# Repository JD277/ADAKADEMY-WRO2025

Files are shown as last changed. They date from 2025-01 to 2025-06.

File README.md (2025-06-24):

## Intro

This is the official Github repository for The Adakademy Team, before known as Adagroup, conformed by Jesser Palma, Jesús Alcalá and Hector Cartagena. This repository contains all the code, documentation, and resources for our project, HALBI. This is our third year participating in WRO

---
# Team Members

* Jesús Alcalá, 20 years old, jdam5000@gmail.com
* Héctor Cartagena, 18 years old, cartagenahector0608@gmail.com
* Jesser Palma, 20 years old, jssrpalma3@gmail.com
---
# Folders structure 
```
ADAKADEMY-WRO2025/
├── models/
├── other/
├── schemes/
├── src/
├── t-photos/
├── v-photos/
└── videos/
```
Where:

- `models`: Every 3D/CAD file used in the car. [view](./models/README.md)
- `schemes`: Wiring diagram, assembly explanation and components description. [view](./schemes/README.md)
- `src`: All code necessary to control the robot. [view](./src/README.md) 
- `t-photos`: team photos. [view](./t-photos/README.md)
- `v-photos`: vehicle photos. [view](./v-photos/README.md)
- `videos`: performance videos of the robot. [view](./videos/README.md)

## Our last prototype
At first, we planned to design the car from scratch, modeling and printing our own 3D pieces, including the chassis and direction, Although it seemed like a good idea at first, as we progressed we started to face problem after problem, we realized that our current design would give us more problems, at the end we tried our best with the time constraints we had, and this was the vehicle we presented at WRO 2024, Cybercooper.

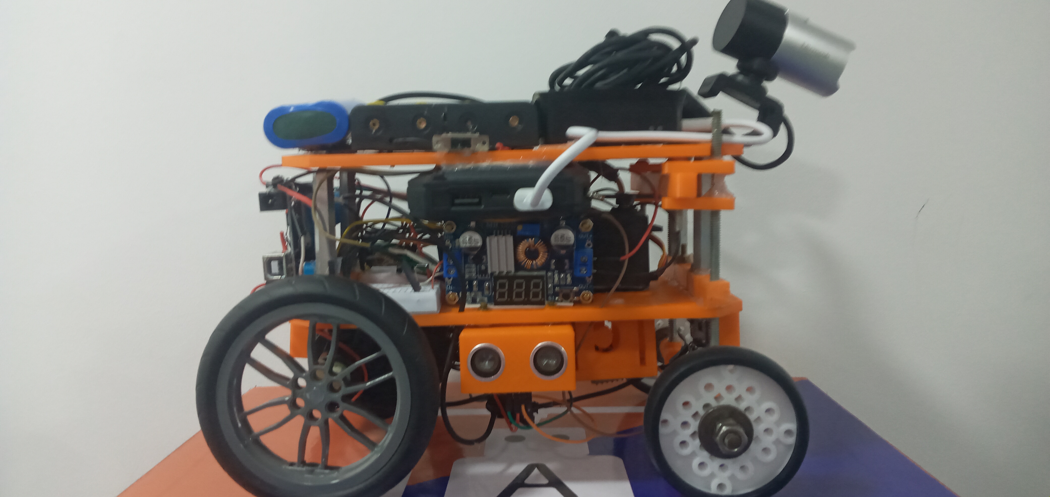
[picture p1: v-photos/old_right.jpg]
cybercooper


## Dark halbi (Our current prototype)

Given the resources we currently had, our main idea was to re-design Cybercooper, modifying the existing base, strategy and using better electronic components; we started printing the new parts with white material and thinking of better ways to assemble the car direction.

At the end, we decided to use a premade base for the chassis, the main reason for this was to save time ( and headaches) with the mechanical design, giving us more time to focus on the electronics and programming.

So we bought the maker kit car from the german enterprise **[Fischertechnik](https://www.fischertechnik.de/de-de/produkte/maker/571900-maker-kit-car)**, now we present a more profesional approach with a better documentation and totally new code sctucture,

<div align="center">

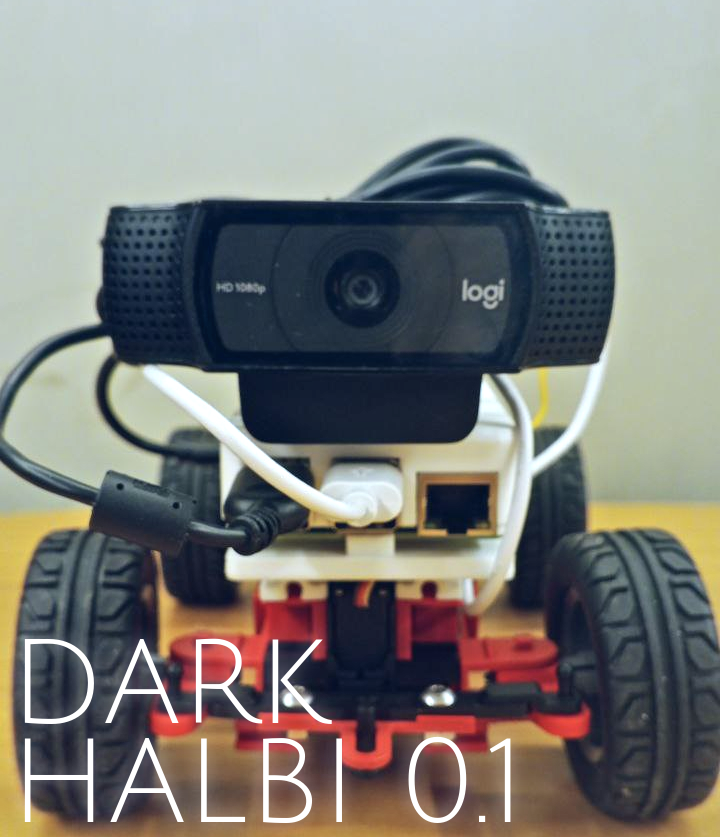
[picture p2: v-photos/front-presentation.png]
dark halbi


</div>

As the kit is made of parts like lego we just design pieces to be compatible with the chassis, after we designed the pieces we fixed the components with screw/glue/Double-side tape. But our inspiration it continues being the Cybertruck of tesla. We have many goals and we are excited about the future because each year we get better to bring betters solutions.

<div align="center">

Cybertruck
</div>

## Mobility

Our vehicle is made the [Ackermann steering mechanism](https://www.youtube.com/results?search_query=ackermann+geometry), which is a geometric  configuration used in vehicle steering systems to ensure that when turning, the inner and outer wheels travel along different radii, preventing tire scrubbing and maximizing cornering stability. This is achieved by steering the front wheels at different angles, with the inner wheel turning at a greater angle than the outer wheel. And is propelled by a differential that we explain with detail here

## Software

We developed the software using python3 as our main programming language and using Thonny/Terminal as code editor.

We wanted to keep the code as simple as possible and use a single language, in order to make this possible we used a library called Pyfirmata which enables us to merge the microcontroller code and the raspberry code in a single unit. 

#### Image Processing

We use the raspberry camera to capture the image, which is converted from BGR format to LAB `(lightness, green-red, blue-yellow)`. We use this colorspace because it's easier to detect the colors, regardless of the environment lighting.

We then use OpenCV to apply a threshold to the image, which returns a mask image with the pixels that reside within the specified color range, we can also reduce processing time by only searching within a specific region of interest on the screen.

### Obstacle Detection

For Obstacle detection, we specify various color ranges that coincide with the color of the obstacles, red and green. After the camera captures the image, we apply gaussian blur and median filters to get a sharper image, the program then applies thresholds to get masks with the colors we are interested in, with this mask we can detected the screen position of the obstacles and the contours of the circuit wall, which can be used to decide the turning direction of the car based on a proportional derivative (PD) algorithm, which involves calculating the differences between the area of the walls.

Looking for more? go to projects folders [Here](#folders-structure) !

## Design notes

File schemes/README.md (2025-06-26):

# Hardware documentation and setup guide
This section provides an overview of the hardware components  used in our autonomous vehicle for the WRO 2025 competition. It includes a detailed description of the electronic and mechanical parts, their specifications, and how they are integrated into the robot’s design. The goal is to document our choices clearly and technically, following the WRO 2025 requirements for engineering transparency and reproducibility. 

## Table of content

* [List of components](#list-of-components)

* [Components description](#components-description)
  
  *  [Raspberry PI 4 B](#raspberry-pi-4-b)

  * [Fischertechnik kit](#fischertechnik-kit)

  * [Li-on 18650 batteries, LX-2BUPS MT3068](#li-on-18650-batteries-lx-2bups-mt3068)

  * [Arduino nano](#arduino-nano)

  * [L298n](#l298n)

  * [Fischertechnik Micro servo Nr. 132292](#fischertechnik-micro-servo-nr-132292)

  * [Ecorder motor 9v Nr. 153422](#ecorder-motor-9v-nr-153422)

  * [Logitech C920X](#logitech-c920x)

* [Assembly](#assembly)
  * [Wiring diagram](#wiring-diagram)
  * [Power description](#power)
  * [Drive](#drive)
  * [3D desing proccess and assembly](#3d-desing-proccess-and-assembly)

* [Recommendations for future fevelopment](#recommendations-for-future-development)
## List of components

<div align="center">

| Quantity | Product | Price| Total |
|---|---|---|---|
| 1 | [Raspberry Pi 4 B](https://www.amazon.com/Raspberry-aleaci%C3%B3n-resistente-refrigerada-ventilador/dp/B07XTRK8D4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) | $110.00 | $110.00 |
| 1 | [Car chassis with motor and servo](https://www.amazon.com/-/es/fischertechnik-Maker-Kit-Car-571900/dp/B0CY31DGT1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) | $152.00 | $152.00 |
| 4 | [18650 Batteries x 2](https://articulo.mercadolibre.com.ve/MLV-822728792-bateria-de-litio-recargable-18650-37v-7800mah-_JM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) | $10.00 | $20.00 |
| 1 | [Webcam logitech](https://www.amazon.com/Logitech-correcci%C3%B3n-funciona-Facetime-port%C3%A1til/dp/B085TFF7M1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) | $70.00 | $70.00 |
| 1 | [MT6068](https://www.amazon.com/-/es/Buying-M%C3%B3dulo-impulso-ajustable-MT3608/dp/B0CWKWX7QC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) | $3.00 | $3.00  |
| 1 | [L298N](https://www.amazon.com/-/es/WWZMDiB-L298N-controlador-Arduino-Raspberry/dp/B0CR6BX5QL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) | $5.00 | $5.00  |
| 1 | [Arduino nano](https://www.amazon.com/-/es/Nano-conexi%C3%B3n-compatible-Arduino-V3-0/dp/B0B42GRG15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) | $10.00 | $10.00 |
| 2 | [LX-2BUPS 5v](https://www.amazon.com/-/es/Bater%C3%ADa-M%C3%B3dulo-Cargador-Tablero-Indicador/dp/B0CGZS38QR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) | $5.24 | $10.48 |
| 2 | [USB cable type C](https://www.amazon.com/paquete-cables-trenzados-iPhone-Samsung/dp/B0DPMQ7291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) | $6.00 | $12.00 |
| 2 | ON OFF Switch | $2.5 | $5.00 |
| 1 | [Indications LEDs](https://www.amazon.com/-/es/MCIGICM-circuitos-experimentos-cient%C3%ADficos-multicolor/dp/B07PG84V17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) | $4 | $4.00 |
| **Total** | | | **$401.48** |

</div>

---

<div style="text-align:justify">

## Components description

### Raspberry PI 4 B  

The Raspberry Pi 4 Model B  is a powerful, credit-card-sized single-board computer (SBC)  developed by the Raspberry Pi Foundation. It is widely used in robotics, IoT projects, and embedded systems due to its versatility, performance, and affordability. 

<div align="center">

Raspberry

</div>

Our strategy is centered on computer vision algorithms developed by us using **[Opencv](https://opencv.org/)** with python, for that reason we have choose this computer given that have a low electrcity consumption (5v 3A) contrary to the pi 5 (5V 5A 😬 To high!) besides is better option that the pi 3 B that we used the last time.

These are the features of our raspberry PI 4:

<div align="center">

| Feature | Description |
|---|---|
| **Type** | Single-Board Computer (SBC) |
| **Processor** | Quad-core Cortex-A72 (ARM v8) @ 1.5GHz |
| **Memory (RAM)** | 8GB |
| **Storage** | microSD card slot |
| **Connectivity** | Wi-Fi 802.11ac (2.4 GHz / 5 GHz), Bluetooth 5.0, Ethernet |
| **USB Ports** | 2 x USB 3.0, 2 x USB 2.0  |
| **Video Output** | 2 x micro-HDMI ports supporting up to 4K resolution |
| **Camera Support** | MIPI CSI camera interface |
| **GPIO Pins** | 40-pin GPIO header (supports I²C, SPI, UART, PWM) |
| **Operating System** | Raspberry Pi OS |
| **Power Supply** | 5V / 3A via USB-C port |

</div>

---
### Fischertechnik kit 
The Fischertechnik Maker Kit Car is a pre-assembled chassis that provides a solid foundation for creating functional models or prototypes of vehicles. It includes essential components such as wheels, motors, axles, and structural elements that allow users to build a stable base for their projects. The kit is compatible with various motors, sensors, and other electronic components, making it ideal for integrating advanced functionalities like autonomous driving, obstacle avoidance, or remote control. The design is modular, enabling easy modifications and upgrades as needed. This flexibility allows users to experiment with different configurations and mechanical setups without needing to start from scratch.

Kits like this are ideal for teams new to robotics because they eliminate the need for extensive mechanical assembly or 3D modeling skills. By using a pre-assembled kit, you can focus on higher-level tasks such as programming, sensor integration, and algorithm development without worrying about building the physical structure from scratch. This approach is particularly beneficial for educational purposes, as it allows students to quickly prototype ideas and test concepts without getting bogged down by mechanical complexities. Additionally, many international teams use similar kits, making it a widely accepted and practical choice for competitions like the World Robot Olympiad (WRO).

<div align="center">

<div style="width:290px">

halbi

</div>
</div>

While pre-assembled kits offer convenience, designing and 3D-printing your own chassis provides several advantages. First, custom chassis designs allow for greater flexibility and optimization, enabling you to tailor the vehicle to specific requirements such as weight distribution, component placement, and cost-efficiency. A well-designed custom chassis can also be more durable and reliable than off-the-shelf kits, which may have fragile parts that are not easily replaceable. Furthermore, creating your own chassis fosters deeper learning in mechanical engineering, CAD modeling, and prototyping—skills that are highly valued in robotics and engineering competitions. While it requires more time and technical expertise upfront, the ability to iterate and refine your design based on testing results leads to a more robust and competitive robot. Ultimately, while pre-assembled kits are great for getting started, building your own chassis offers superior customization, cost savings, and educational value, making it the preferred choice for advanced teams aiming to push the boundaries of innovation in the WRO FE category.

---
### Li-on 18650 batteries, LX-2BUPS MT3068

The robot uses two 18650 Li-ion batteries  combined with an LX-2BUPS MT3068 power management module , which allows the system to function without complex circuitry or custom-built charging solutions. This setup provides a stable power source for both the Raspberry Pi and motor driver, making it suitable for teams without advanced electronics experience. The LX-2BUPS module acts as a UPS (uninterruptible power supply), ensuring smooth transitions between charging and discharging states. However, this configuration has some limitations: the 18650 batteries are relatively large, making space management within the chassis challenging. Additionally, these batteries have limited runtime when powering high-consumption components like the Raspberry Pi, especially during intensive tasks such as image processing. 

To address voltage requirements for the motors, we included a step-up module to boost the output to 11.24V , allowing the motors to operate at optimal speed. While this setup works well for basic operation, it lacks a Battery Management System (BMS) , meaning there’s no automatic balancing of charge between the two batteries. As a result, one battery may discharge faster than the other, potentially leading to unstable power delivery or overheating. Despite its drawbacks, this energy solution was chosen because our team lacked the expertise to design and implement a more advanced Li-Po-based system from scratch. It serves as a functional starting point that enables us to focus on software and sensor integration while preparing for future improvements through custom-designed power circuits. 

<div align="center">

<div style="width:290px">

LX2-BUSB

mt3068

</div>
</div>

---
### Arduino nano
For our autonomous vehicle project, we chose the Arduino Nano with USB-C  as the primary microcontroller to handle sensor inputs, motor control, and coordination with the main Single-Board Computer (SBC), such as a Raspberry Pi. This decision was driven by both practical and ergonomic considerations—primarily, our team’s preference for the USB-C interface , which offers better durability, faster data transfer, and reversible plug orientation compared to older micro-USB connectors. 

While the Arduino Nano (USB-C version) is not strictly required for this project, its compact size, wide community support, and compatibility with the Firmata2 protocol  made it a natural fit for rapid prototyping and integration with Python-based control logic running on the SBC. 
this are some features from our arduino :
<div align="center">

| Feature | Description |
|---|---|
| **Type** | Microcontroller board |
| **Microcontroller** | ATmega328P (Nano v3) |
| **Clock Speed** | 16 MHz |
| **Flash Memory** | 32 KB (0.5 KB used by bootloader) |
| **SRAM** | 2 KB |
| **EEPROM** | 1 KB |
| **Digital I/O Pins** | 14 (of which 6 provide PWM output) |
| **Analog Input Pins** | 8 channels with 10-bit resolution |
| **Power Supply** | 5V regulated input |
| **Input Voltage (recommended)** | 7–12V |
| **Current Draw (typical)** | ~20 mA |
| **Communication Interfaces** | UART, SPI, I²C |
| **Programming Language** | C/C++ using Arduino IDE or PlatformIO |

<div style="width:290px">
</br>

nano

</div>

</div>

---
### L298n
The L298N H-Bridge module  is a dual motor driver commonly used in robotics to control the direction and speed of DC motors. It allows bidirectional motor control using Pulse Width Modulation (PWM) signals from microcontrollers like Arduino or Raspberry Pi. This makes it ideal for basic robotic platforms where simplicity and ease of use are prioritized over high efficiency. 

While the L298N is user-friendly and widely available, it has some limitations such as high voltage drop  (around 1.5V–3V per motor), which reduces the effective voltage delivered to the motors. This can affect performance, especially when using lower-voltage batteries. Additionally, it tends to generate significant heat , often requiring heatsinks or cooling solutions during prolonged operation. We don't opt for more efficient drivers like the DRV8833  or TB6612 , which offer better energy efficiency and thermal performance because find or deliver those drivers for Venezuela is very hard. However, for early development and testing, the L298N remains a solid choice due to its ease of integration and widespread community support.

<div align="center">

<div style="width:290px">

L298N

</div>
</div>

---
### Fischertechnik micro servo Nr. 132292
A servomotor  (or servo) is a type of motor commonly used in robotics, automation, and control applications where precise angular positioning  is required. Unlike regular DC motors that rotate continuously, servos are designed to move to a specific angle and hold that position until instructed otherwise.

A standard **servomotor** consists of:

1. **DC Motor**: Provides rotational force.
2. **Gear Reduction System**: Slows down the motor’s rotation and increases torque.
3. **Position Sensor (Potentiometer)**: Monitors the current shaft position.
4. **Control Circuitry**: Compares the desired position with the actual one and adjusts the motor accordingly.

Servos receive **control signals** through Pulse Width Modulation (PWM). The width of the pulse determines the angle the motor should turn to:

- **~50 Hz signal (every 20 ms)**
- **Pulse width determines position:**
  - `1.0 ms` → ~**0°**
  - `1.5 ms` → ~**90° (neutral)**
  - `2.0 ms` → ~**180°**

This makes servos ideal for our ackerman direction. Here are some features from that servo:

<div align="center">

| Feature | Description |
|---|---|
| **Voltage Range** | 4.8V – 6.0V |
| **Control Signal** | PWM (Positive Edge Triggered) |
| **Neutral Position** | Approx. 1500 µs (microseconds) |
| **Rotation Angle** | ~60° ±10° |
| **Torque @ 4.8V** | 1.8 kg·cm |
| **Torque @ 6.0V** | 2.2 kg·cm |
| **Speed @ No Load** | 0.13 sec/60° at 4.8V / 0.11 sec/60° at 6.0V |
| **Dead Band Width** | 8 µs |
| **Current Consumption (Idle)** | 200 mA stopped / 1000 mA running (no load) |
| **Wire Length** | 240 mm |
| **Plug Type** | JR Universal (Brown = GND, Red = VCC, Orange = Signal) |

<div style="width:290px">
</br>

Servo

</div>
</div>

**NOTE:** You can use other servo if you can adapt it to the kit but you don't have to use exact the same 

---
### Ecorder motor 9v Nr. 153422

An **encoder motor** is a DC motor equipped with an **integrated encoder**, which allows for **precise measurement of rotation speed, direction, and position**. This feedback makes it ideal for applications that require accurate motion control, such as autonomous navigation, distance estimation, or path correction. The encoder generates electrical pulses as the motor shaft rotates, and by counting these pulses, the robot can determine how far it has traveled or how fast it is moving, but we're only using the motor wihtout sensing the position of the motor.

Here are the motors features:

<div align="center">

| Feature | Description |
|---|---|
| **Supply Voltage** | 9V DC (motor side), 3.3–9V DC (encoder side) |
| **Encoder Type** | Push-Pull Output (0/9V), max. 10 mA |
| **Resolution** | 3 pulses per motor revolution (or 6 when counting both rising and falling edges) |
| **Gear Ratio** | 1:21.3 |
| **Encoder Frequency** | Up to 1 kHz |
| **Signal Interface** | 3-pin header |
| **No-Load Speed** | ~200 rpm (±22) at 9V |
| **Stall Torque** | 1.3 kg·cm minimum |
| **Stall Current** | 1.3A maximum |

<div style="width:290px">
</br>

Encorder

</div>
</div>

---
### Logitech C920X

The **Logitech C920X** is a high-definition USB webcam designed for video conferencing, streaming, and general-purpose imaging applications. It features a **1080p HD sensor** with autofocus, built-in microphone array, and compatibility with most operating systems, making it a versatile vision sensor for robotics projects.

In our autonomous vehicle setup, we use the **C920X as the primary camera** for visual perception tasks such as:
- Line detection (blue and orange lines)
- Obstacle avoidance
- Traffic sign recognition
- Parking alignment using color-based segmentation

<div align="center">

| Feature | Specification |
|---|---|
| **Resolution** | Full HD 1080p at 30 fps |
| **Autofocus** | Yes – allows sharp image capture even while moving |
| **Microphone** | Built-in stereo microphones |
| **Compatibility** | Works with Windows, Linux, macOS |
| **Interface** | USB 2.0/3.0 (plug-and-play) |
| **Mounting Options** | Clip-on or tripod mount |
| **Field of View** | 78° diagonal field of view (ideal for line detection) |

</div>

Thanks to its **UVC (USB Video Class)** compliance, the C920X can be used directly with OpenCV and Python on platforms like Raspberry Pi without requiring special drivers. This makes it ideal for real-time image processing and autonomous decision-making in robot vehicles.

Although not originally designed for robotics, the C920X has become a popular choice among teams due to its affordability, reliability, and ease of integration with Single Board Computers (SBCs) like **Raspberry Pi**.

#### 🚫 Limitations

- **Fixed Focus:** While it has autofocus, lighting conditions affect performance significantly.
- **No Hardware Trigger:** Not ideal for synchronized sensor fusion but acceptable for basic vision tasks.
- **Size and Weight:** Slightly bulkier than alternatives like the Arducam or Raspberry Pi HQ Camera.

Despite these limitations, the **Logitech C920X** serves as an excellent starting point for building a functional vision system in the WRO 2025 competition.

<div align="center">

<div style="width:290px">

camera

</div>
</div>

---
## Assembly

To test new ways to achieve the goal and win the competition, we make a lot of investigation watching videos, others teams repositories we choose the [Maker kit car from Fischertechnik](https://www.fischertechnik.de/de-de/produkte/maker/571900-maker-kit-car) , and after testing we could notice this about our election:

- The chassis have many fragile parts.
- Have a deviation on the direction because the wheels oscillate. 
- The wheels axis are made from plastic so if you put much weight it will broke. 

So if you're starting we recommend it but we determine is better inversion to model your own chasis.

Leaving that aside, we decided to use a premade base for the chassis, the main reason for this was to save time ( and headaches) with the mechanical design, giving us more time to focus on the electronics and programming.

<div align="center">

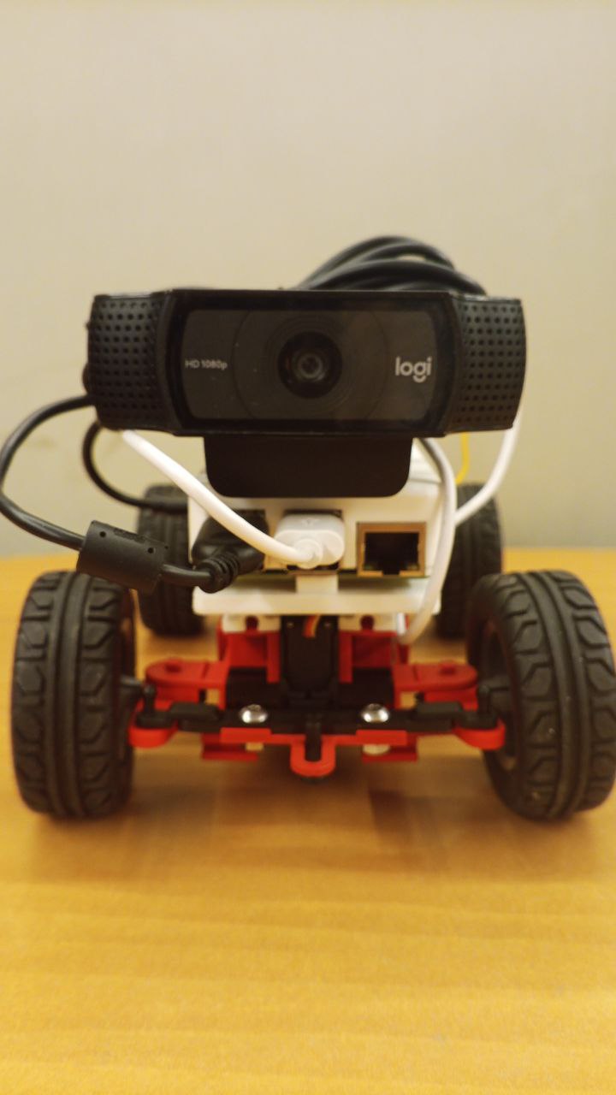
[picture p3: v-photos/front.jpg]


</div>

For the assembly we are gone suppose that you have follow the assemble instructions of the [company](https://apps.fischer.de/ecom/fischertechnik/digitale-bauanleitungen/maker-kit-car.htm), **please take in count that maybe you will have to use glue in some parts of the kit car** because the are some parts like the servo axis that are easy to remove and with the vibration it will expulse the pieces that aren't fixed pieces

---

### Wiring diagram

Remember to buy every component before start building

<div align="center">

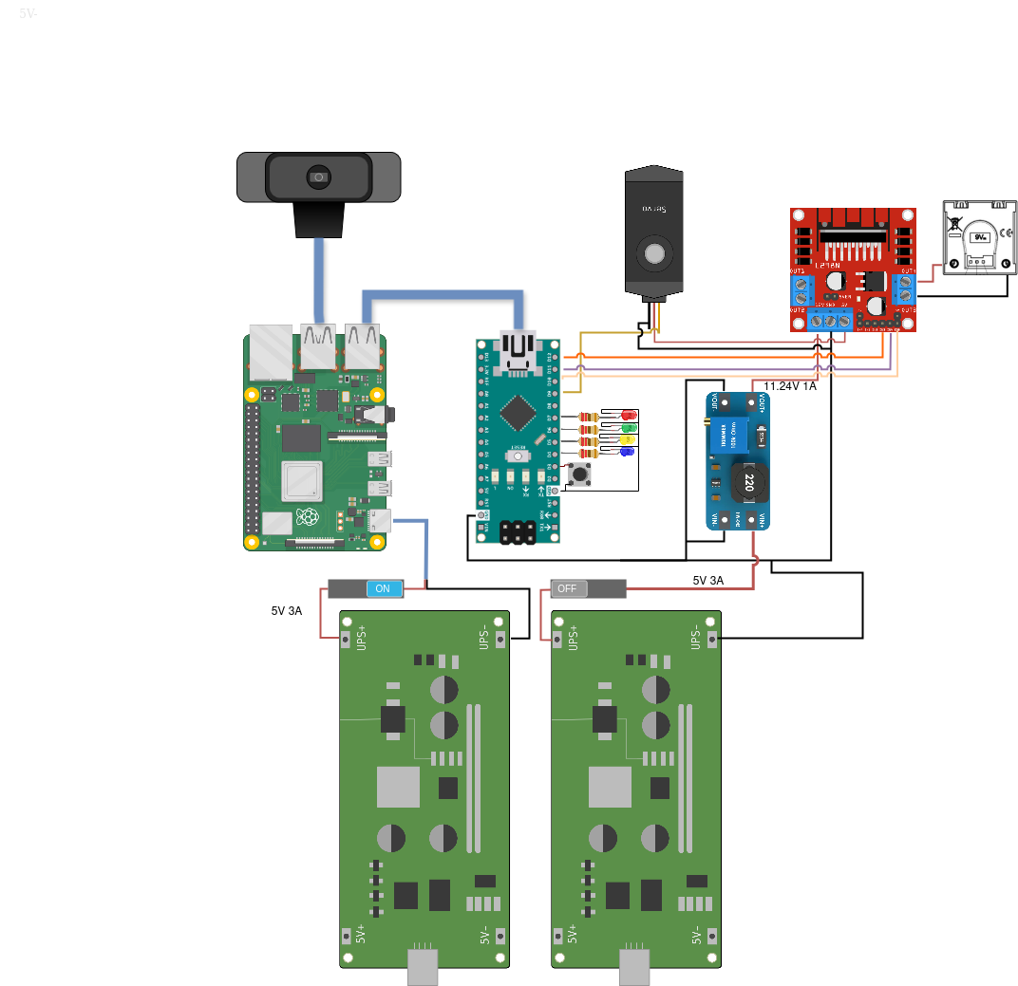
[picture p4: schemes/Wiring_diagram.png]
cables


</div>

--- 

### Power

A short explanation of the power supply hierarchy of the robot

- 18650 battery `3.7v 2000mAh` x 2
  - LX-2BUPS `5V 3A`
    - Raspberry PI 4 `5v 3A`
      - Arduino nano `5v` powered by USB C cable
      - Logitech camera
    
- 18650 battery `3.7v 2000mAh` x 2
  - LX-2BUPS `5V 3A`
    - MT3068 `5v 3A` --> `11.24v 1A`
      - L298N `12v MAX` 
        - Micro Servo `5v`
        - Encorder motor `9v`

### Drive

The kit use an simple Ackerman direction powered by a servo with 1.8kgcm standing torque, said direction is a geometric design principle used in vehicles to ensure that both front wheels turn at different angles when making a turn, allowing the vehicle to move smoothly around corners without skidding. This system uses a linkage setup that enables the inner wheel to turn sharper than the outer wheel, following the natural arc of the turn. In the Fischertechnik Maker Kit Car , the Ackermann steering mechanism is implemented using a set of tie rods connected to the front wheels. [We recommed this video to learn more about it](https://www.youtube.com/watch?v=hsQO5C0adQk)

While the propulsion is made by a mechanism called "diferential" wich  Maker Kit includes, is a mechanical system that allows the driven wheels of the vehicle to rotate at different speeds while receiving power from the same source. This is essential for smooth turning, as it enables one wheel to move faster than the other when the vehicle corners, preventing skidding and reducing tire wear. In the context of the WRO 2025 FE category, this type of differential is typically used in rear-wheel-drive configurations where an electric motor powers both rear wheels through a shared axle. While the kit’s differential simplifies the drivetrain design and improves maneuverability, it may not be suitable for advanced autonomous driving tasks due to its mechanical limitations and potential lack of precision control compared to software-based or independent motor control.

<div align="center">

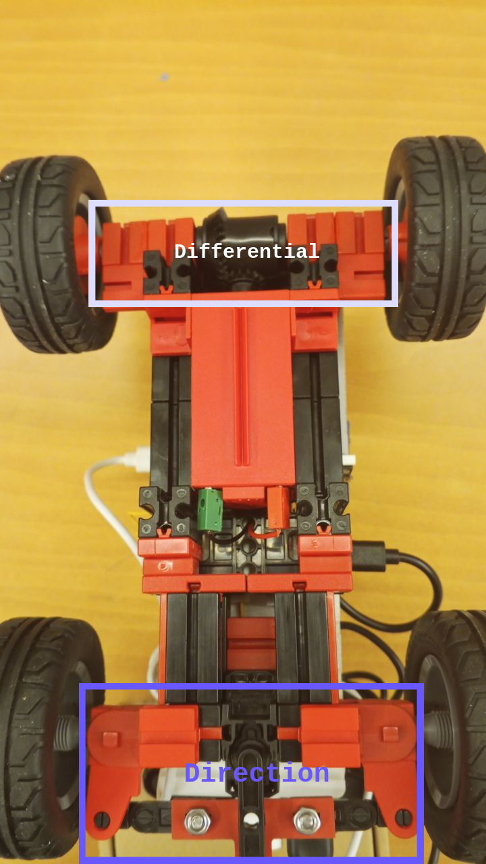
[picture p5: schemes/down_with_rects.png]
down


</div>

### 3D desing proccess and assembly

We bought the chasis and it arrives 2 months later, at the beggining we get scared because of the space so we begin to think how to save space to place every component.

After days and a lots of headaches we find the solution to put every component.

the front part of our car is essentially the [raspberry case]() elevated with [extension parts](../models/Extension%20base.3mf) desingned by our own, upper to RPI is the camera fixed with double-sided tape. The RPI is located in a way that you could use the USB ports, we choose this because we have two components that need the USB connection.

<div align="center">

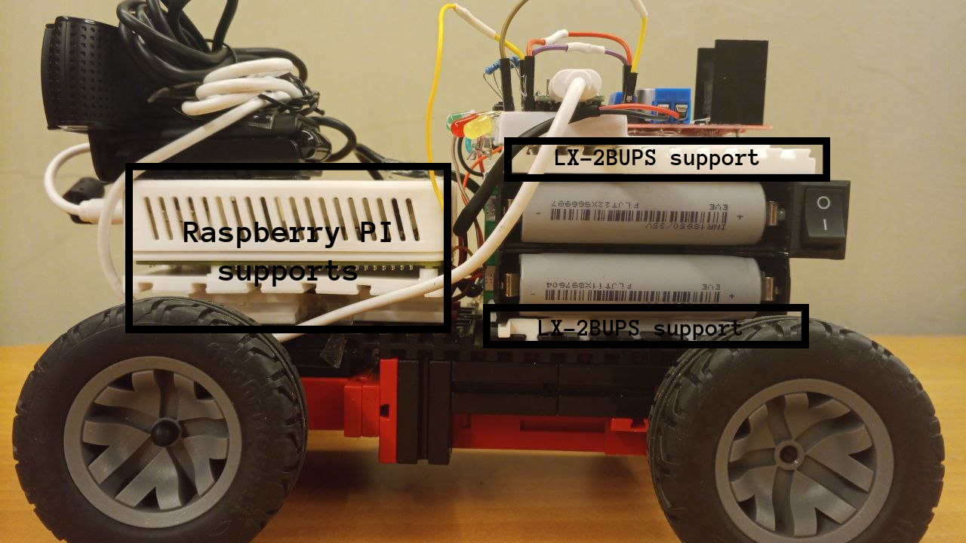
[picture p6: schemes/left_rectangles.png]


</div>

For the UPS modules we have model two supports that join both powersupply and hides almost every connection, the down part join the fits in the chasis of the maker kit car but before to put the modules you have to solder the switchs and the cables.

<div align="center">

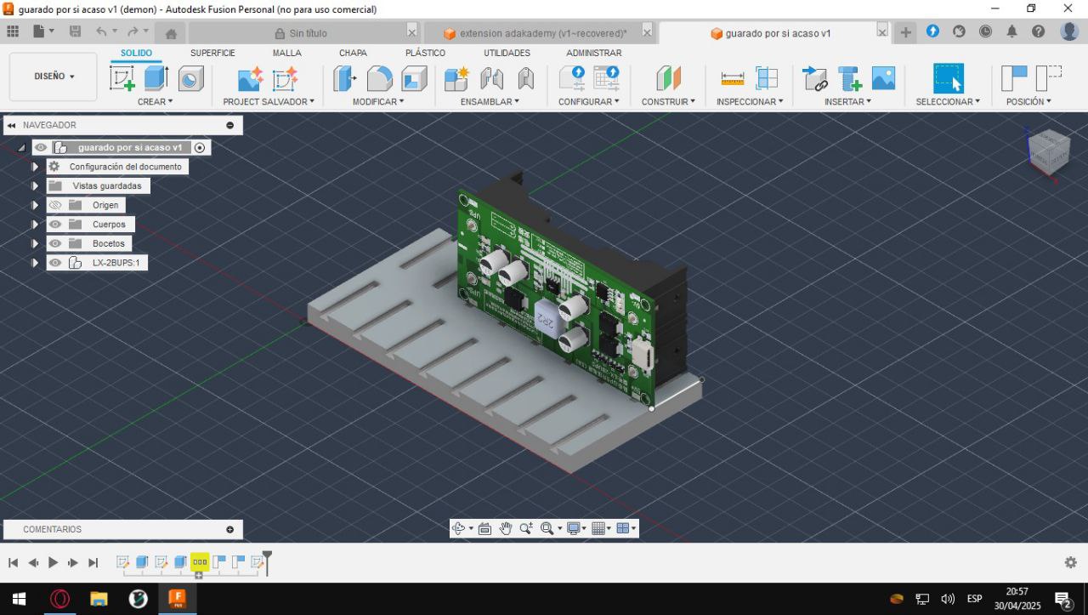
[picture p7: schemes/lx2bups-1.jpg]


</div>

In our case we fixed the switchs with industrial glue but you can do some 3d print holder for it. The top part is used as base for the nano, l298n module (wich have its own base to fit in the other one), and the mt3608.

<div align="center">

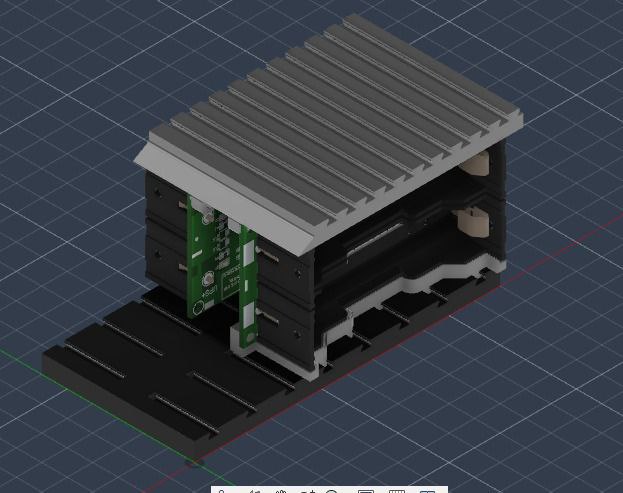
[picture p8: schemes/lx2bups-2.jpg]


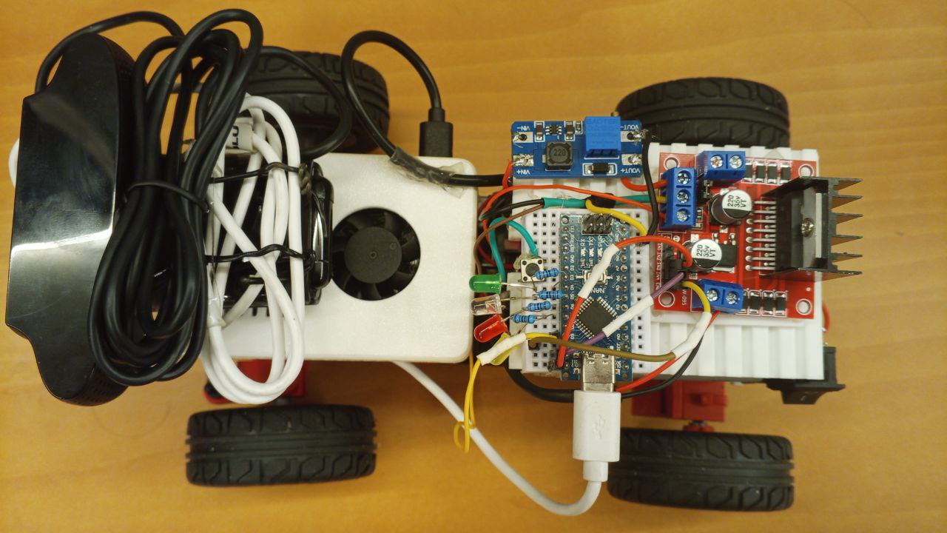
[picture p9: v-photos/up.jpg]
up


</div>

## Recommendations for future development  

As a recommendation for other teams, we suggest two key improvements to enhance both the performance and compactness of your autonomous vehicle: 

  * Design a Custom PCB: 
    Creating your own custom printed circuit board (PCB)  allows you to integrate all essential electronics — such as motor drivers, voltage regulators, microcontroller, and sensor interfaces — into a single, compact board tailored to your robot’s needs. This not only reduces the overall size but also improves reliability by minimizing loose connections and simplifying wiring. 

  * Use a LiPo Battery with Dedicated Charger: 
    Replacing standard battery packs with a LiPo (Lithium Polymer) battery  and using a dedicated charging circuit can significantly reduce weight and space usage while offering better power efficiency. LiPo batteries provide higher energy density and longer runtime, which is especially beneficial in high-drain applications like motor control and onboard computing. 

These are our goals for improvement in the next season, and we believe they will help us build a more efficient and competition-ready vehicle. 

Additionally, we recommend conducting thorough research and planning  before purchasing components. Doing a deep investigation on each part — including compatibility, power requirements, and long-term usability — helps avoid unnecessary expenses and ensures every component contributes meaningfully to the final design. 

<div>

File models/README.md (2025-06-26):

# Content
## First Prototype
- Lower Chasis
- Direction
## Fischertechnik kit
- LX-2BUPS down base
- L298n Base
- Top Base
- Base extension
- Raspberry4_Base
- wheel nut

# Overview
In this file will be the explanation of the models used for the proyect

## *First prototype (Cooper White)*
- This was the version we design in case the chasis didn´t come in time

Cooper White

## *Fischertechnik kit (The final chasis)*
- althought the chasis we planned initially did come in time 
Fischertechnik kit

##  Folder structure
The models files are organized with this order:
```
ADAKADEMY-WRO2025/models/
├── LX-2BUPS_Down_Base.3mf
├── L298N_Base.3mf
├── Top_Base.3mf
├── Wheel_nut.3mf
├── Raspberry4_Base.3mf
└── Base_Extension.3mf
```
Where:

- `/LX-2BUPS_Down_Base.3mf`: Model used to connect the LX-2BUPS module to the chassis
- `/L298N_Base.3mf`: Model used to connect the l298n module to the chassis
- `/Top_Base.3mf`: Top extension model to connect more modules to the chassis
- `/Wheel_nut.3mf`: Nut to adjust the wheels to the axle
- `/Raspberry4_Base.3mf`: Models to connect and protect the Raspberry 4 Model B to the chassis
- `/Base_Extension.3mf`: Extension model to increase the height of components by 10 mm

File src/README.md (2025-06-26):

# Software documentation

This section provides an overview of the software architecture  used in our autonomous vehicle for the WRO 2025 Futuros Ingenieros  competition. It includes:

* The programming languages and tools used

* A high-level description of the system's modules

* How the robot processes sensor data, makes decisions, and controls hardware

* Integration with vision systems (e.g., line detection, traffic sign recognition)

* Communication between controllers (e.g., Raspberry Pi ↔ Arduino Nano)

# Folders structure 
```
ADAKADEMY-WRO2025/src/
├── modules/
|    ├── board.py
|    ├── vision.py
|    └── halbi.py
├── utils/
|    ├── movement_test.py
|    ├── color_tester.py
|    └── vision_test.py
├── constants.py
├── open_challenge.py
└── obstacle_challenge.py
```
Where:

- `modules/board.py`: This is ArduinoController class manages Arduino hardware (LEDs, buzzers, servos, and motors via a L298N driver) using pyfirmata2.

- `modules/vision.py`: To Capture and process images to detect colored objects within a region of interest (ROI) using a Raspberry Pi camera.

- `modules/halbi.py`: Is the main class compossed by the other to that is used to program both challenges, this class is configured to be easy to program your car without worrying about complex stuff. 

- `utils/movement_test.py`: Is an implementation with pygame that allows you to control the car like an FPV car to test everything related with the movement.

- `utils/color_tester.py`: Is an opencv code to calibrate the mask that will be detected. This file was recover from [ASPARAGUS team](https://github.com/kylln20/WRO_FE_2023-24/blob/main/src/ColourTesterLAB.py) which has the fifth place on the international of 2024

- `utils/vision_test.py`: Is used to see how the masks are working and finish the calibration process 

- `constants.py`: Are all the values that don't change like arduino pins, indicators leds

- `open_challenge.py`: is the final code for the first challenge.

- `obstacle_challenge.py`: is the final code for the second challenge.

**Note:** to run any file of the project you have to do this first: 

- Clone the repo
```bash
git clone  https://github.com/JD277/ADAKADEMY-WRO2025.git
```
- Install dependencies
```bash
pip install opencv-python numpy pyfirmata2
```

- Move to the project folder
```bash
cd ADAKADEMY-WRO2025
```

- excute the file that you want using this structure (remember to upload standarfirmata.ino to your nano! Check it [here](https://www.youtube.com/watch?v=RS35q6ksU6w&list=PLY1rn9AjOKu0FGn8SNnd4FJ-BG-Qqnkti))
```bash
python3 -m src.open_challenge
```

This way to execute the files is because we need that python read the folders as modules that is the reason of the init files in the directories because with that python understands how to use the imported files as a packages. 

## Table of contents

* [New code vs Past code](#new-code-vs-old-code)

* [Code description](#code-description)

* [Calibration](#calibration)

- [Open challenge](#open-challenge)
  - [Strategy](#open-challenge-strategy)
  - [Flowchart](#open-challenge-flowchart)
  - [Explanation](#open-challenge-explanation)
  - [Recommendations](#open-challenge-recommendations)
- [Obstacle challenge](#obstacle-challenge)
  - [Strategy](#obstacle-challenge-strategy)
  - [Flowchart](#obstacle-challenge-flowchart)
  - [Explanation](#obstacle-challenge-explanation)
  - [Recommendations](#obstacle-challenge-recommendations)

<div align="justify">

## New code vs Old code
Before to start explaining our code we like to show our improvements compared with the last year.

the last year we used a code wich use POO and funcional programming in C++ on Arduino IDE but all the code was in only one file with a lot of lines that difficulted to implement new things and debugging, with that we learn we need to go back two steps to continue and we focus to learn python/C++, POO, algortihms in a very deep way.

With this we re-read our code and begin to enchance our code taking the class for Serial comunication that we made, and we decided (after getting a new raspberry) to make all our code based on firmata protocol, we made this beacuse for debugging is easier to review one code than two in differents languages and as one of us don't donminates C++ we choose python.

That selection let us to create a better way to organize everything and now we can show a profesional work with a POO using pydoc comments.

## Code description

This is a complete description of every class attribute and method with its args, we recommend to see this first before to jump to the others section and when you clone the repository use this as guide to navigate in our code.

---
 
### board.py (class ArduinoController) 

#### Dependencies  
- `time`  
- `pyfirmata2`  
- `src.constants`

#### Description of the constructor method

```python
    def __init__(self, port=None):
        """
        Initializes the connection with Arduino.
        If no port is specified, it attempts to autodetect.
        """
        # If port is not provided, auto_setup returns the proper port
        self.board = pyfirmata2.Arduino(port)

        # Start the iterator to continuously read data from Arduino
        self.iterator = pyfirmata2.util.Iterator(self.board)
        self.iterator.start()

        # Dictionaries to store components
        self.servos = {}
        self.motors = {}
        self.leds = {}
        self.buzzers = {}
        self.buttons = {}
```

The constructor initializes the Arduino board using the provided port or auto-detects it if none is given. It also starts an iterator thread for continuous data reading and initializes dictionaries to store various components (LEDs, servos, motors, buzzers, buttons).  

---

#### Attributes description:  

<div align="center">

|Attribute|Datatype|Functionality|
|---|---|---|
|`board`|`pyfirmata2.Arduino`|Represents the connection to the Arduino board.|
|`iterator`|`pyfirmata2.util.Iterator`|Thread that continuously reads data from the Arduino.|
|`servos`|`dict[int, pyfirmata2.Pin]`|Stores servo motor objects indexed by their pin number.|
|`motors`|`dict[str, dict]`|Stores DC motor configurations, indexed by motor ID. Each entry includes in1, in2, and enb pins.|
|`leds`|`dict[int, pyfirmata2.Pin]`|Stores LED objects indexed by their pin number.|
|`buzzers`|`dict[int, pyfirmata2.Pin]`|Stores buzzer objects indexed by their pin number.|
|`buttons`|`dict[int, pyfirmata2.Pin]`|Stores button objects indexed by their pin number.|

</div>

---

#### Method description:  

<div align="center">

|Method|Args|Return|Description|
|---|----|---|---|
|`setup_led()`|`pin: int`|None|Configures a digital output pin for an LED and stores it in `self.leds()`.|
|`led_on`|`pin: int`|None|Turns on the LED connected to the specified pin.|
|`led_off()`|`pin: int`|None|Turns off the LED connected to the specified pin.|
|`setup_buzzer()`|`pin: int`|None|Configures a digital output pin for a buzzer and stores it in `self.buzzers`.|
|`buzzer_on()`|`pin: int`|None|Activates the buzzer connected to the specified pin.|
|`buzzer_off()`|`pin: int`|None|Deactivates the buzzer connected to the specified pin.|
|`setup_servo()`|`pin: int`|None|Configures a servo motor on the specified pin and centers it.|
|`set_servo_angle()`|`pin: int`, `angle: float`|None|Sets the angle of the servo motor (0–180 degrees).|
|`setup_motor()`|`in1_pin: int`, `in2_pin: int`, `motor_id: str`, `enb_pin: int`|None|Configures a DC motor using DRV8833/L298N driver and stores it in `self.motors`.|
|`set_motor_speed()`|`motor_id: str`, `speed: int`|None|Controls the speed and direction of the motor (-255 to 255).|
|`setup_button()`|`pin: int`|None|Configures a button with internal pull-up resistor and enables state reporting.|
|`button_callback()`|`data`, `pin: int`|None|Callback triggered when the button state changes; updates the button's state.|
|`is_button_pressed()`|`pin: int`|`bool`|Returns `True` if the button is released (HIGH), `False` if pressed (LOW).|
|`interactive_test_menu()`|None|None|Provides a console-based menu to interactively test all connected components.|
|`close()`|None|None|Stops the iterator and closes the connection to the Arduino board.|

</div>

---

#### vision.py (class VisionController)

#### Dependencies  
- `cv2` (`cv`)  
- `numpy` (`np`)  
- `src.constants`

#### Description of the constructor method

```python
def __init__(self, usb_port):
    """
    Initialize the vision controller with the desired resolution

    Args:
        width: is the widness of the cam resolution
        height: is the the high of the cam resolution
    """
    self.image_width  = 640
    self.image_height = 480
    self.image_lab = 0
    self.frame = any
    self.camera_cap = cv.VideoCapture(usb_port)
    self.camera_cap.set(cv.CAP_PROP_FRAME_WIDTH, self.image_width)
    self.camera_cap.set(cv.CAP_PROP_FRAME_HEIGHT, self.image_height)
```

The constructor initializes a video capture object using OpenCV to interface with the USB camera connected at the specified port. It sets the resolution to 640x480 by default and prepares internal variables for storing raw frames and processed LAB images.

---

#### Attributes description:  

<div align="center">

|Attribute|Datatype|Functionality|
|---|---|---|
|`image_width`|`int`|Stores the width of the camera resolution. Default is 640 pixels.|
|`image_height`|`int`|Stores the height of the camera resolution. Default is 480 pixels.|
|`image_lab`|`numpy.ndarray` or `int`|Stores the current image in LAB color space after processing. Initially set to `0`.|
|`frame`|`numpy.ndarray` or `any`|Stores the most recent raw frame captured from the camera.|
|`camera_cap`|`cv.VideoCapture`|OpenCV VideoCapture object used to interface with the USB camera.|

</div>

---

#### Method description:  

<div align="center">

|Method|Args|Return|Description|
|---|----|---|---|
|`receive_image()`|None|None|Captures a frame from the camera, stores it in `self.frame`, converts it to LAB color space and applies Gaussian blur.|
|`draw_roi(roi)`|`roi`: ROI object with `x1`, `y1`, `x2`, `y2`|None|Draws a green rectangle on the current frame representing the region of interest (ROI).|
|`draw_contours(cnt, roi, color)`|`cnt`: contour data<br>`roi`: ROI object<br>`color`: tuple (B, G, R)|None|Draws detected contours inside the specified ROI on the current frame.|
|`find_contours(range, roi)`|`range`: list of lower/upper color bounds<br>`roi`: ROI object|`list` of contours|Detects and returns contours within a given color range and region of interest using LAB color space and morphological operations.|
|`max_contour(contours, roi)`|`contours`: list of contours<br>`roi`: ROI object|`list` `[area, x, y, contour]`|Finds and returns the largest valid contour along with its area and center coordinates relative to the full camera frame.|

</div>

--- 

### `halbi.py` (class HALBI)

#### Dependencies  
- `src.modules.vision.VisionController`  
- `src.modules.board.ArduinoController`  
- `src.constants`

---

#### Description of the constructor method

```python
def __init__(self, serial_port: any, camera_port: any):
    """
        
    """
    self.vision = VisionController(camera_port)
    self.board  = ArduinoController(serial_port)

    self.turns: int = 0
    """Number of turns the car has made in the circuit"""

    self.first_color_detected : int = 0
    """First color that the camera detected\n 
    0 = None
    1 = Red, 
    2 = Green, 
    3 = Blue,
    4 = Orange
    """

    self.turning_direction: int = 0
    """Direction that the car will be running in, this will by determined by the vision controller\n
    1 = Left,
    2 = Right,
    0 if the camera hasn't detected the direction."""

    self.DEBUG_MODE = True
    """Optional mode for debugging"""
```

The constructor initializes both the `VisionController` and `ArduinoController` with the provided serial and camera ports. It also sets up internal state variables to track the robot's behavior such as number of turns, detected color, turning direction, and debug mode.

---

#### Attributes description:  

<div align="center">

|Attribute|Datatype|Functionality|
|---|---|---|
|`vision`|`VisionController`|Interface to manage image capture and processing from the camera.|
|`board`|`ArduinoController`|Interface to control hardware components via the Arduino board.|
|`turns`|`int`|Counts how many turns the car has performed during navigation.|
|`first_color_detected`|`int`|Indicates the first color detected by the vision system (`0`: none, `1`: red, `2`: green, `3`: blue, `4`: orange).|
|`turning_direction`|`int`|Stores the current turning direction (`0`: not set, `1`: left, `2`: right).|
|`DEBUG_MODE`|`bool`|Enables or disables debug features like interactive testing menus.|

</div>

---

#### Method description:  

<div align="center">

|Method|Args|Return|Description|
|---|----|---|---|
|`setup_HALBI(pins)`|`pins: dict`|None|Rapidly configures all necessary pins on the Arduino for LEDs, motor, servo, buzzer, and button. Raises an error if any required pin is missing.|
|`Stop()`|None|None|Stops the motor, centers the servo, and turns off all LEDs. Used to safely halt HALBI's movement.|
|`Start()`|None|`bool`|Returns the current state of the start button. Typically used to detect when the user presses it to begin operation.|
|`go_forward(speed)`|`speed: int = 255`|None|Moves the car forward at the specified speed. Also updates LED indicators accordingly.|
|`go_backward(speed)`|`speed: int = 255`|None|Moves the car backward at the specified speed. Also updates LED indicators accordingly.|
|`turn_left()`|None|None|Turns the steering to the left and activates appropriate LED feedback.|
|`turn_right()`|None|None|Turns the steering to the right and activates appropriate LED feedback.|
|`turn_direction()`|None|None|Applies the stored turning direction (`left`, `right`, or `center`) based on `self.turning_direction`.|
|`turn_center()`|None|None|Centers the steering servo to neutral position and adjusts LEDs.|
|`_test()`|None|None|Internal method for testing components; only runs if `DEBUG_MODE` is enabled. Currently calls the ArduinoController's test menu.|
|`close()`|None|None|Safely closes the connection to the Arduino board. Should be called before exiting the program.|

</div>

---

## Calibration

For the calibration this is the process that we suggest to make the car working properly.

1. Hardware:

Ensure that every components is connected like the [wire diagram](../schemes/Wiring_diagram.png) , and test if all mechanics parts are placed fine.

2. Movement test:

To test the movement you can use the `movement_test.py` file you just have to connect your car to one hdmi screen to start pygame correctly and excute: 

```bash
python3 -m src.utils.movement_test.py
```

And now you can use the car like an FPV car that you can control with WASD keys, if everything is working.
**Note:** Remember to turn on the car motors 

3. Mask configutation
Now you have to calibrate the colors mask using the color tester, so you have to modify the masks that are on constants.py file, so excute, modify and test!

```bash
python3 -m src.utils.color_tester color_name
```
this is what should see after calibration (in this case we are using black color)

<div align="center">

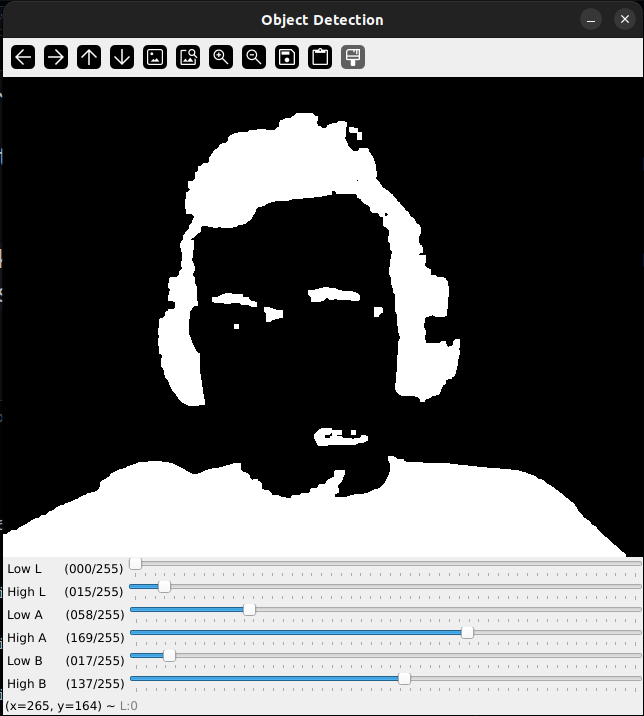
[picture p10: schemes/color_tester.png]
Color tester


</div>

You must do this with every color!! And with this now you can just start to evaluate your robot for the WRO competition

---

## Open challenge
### Strategy

As our car have a camera with little field of view (78°), we can't manage the internal walls because th car would enter on infinite loop of turns, so as our car is small and the direction is very accurate, the car just keep moving forward waiting to reach the a thresh with greater than 30000 black pixeles with one line (blue or orange).

With this we don't have to worry about the internal walls because we will always in the outside lane.

### Flowchart
<div align="center">

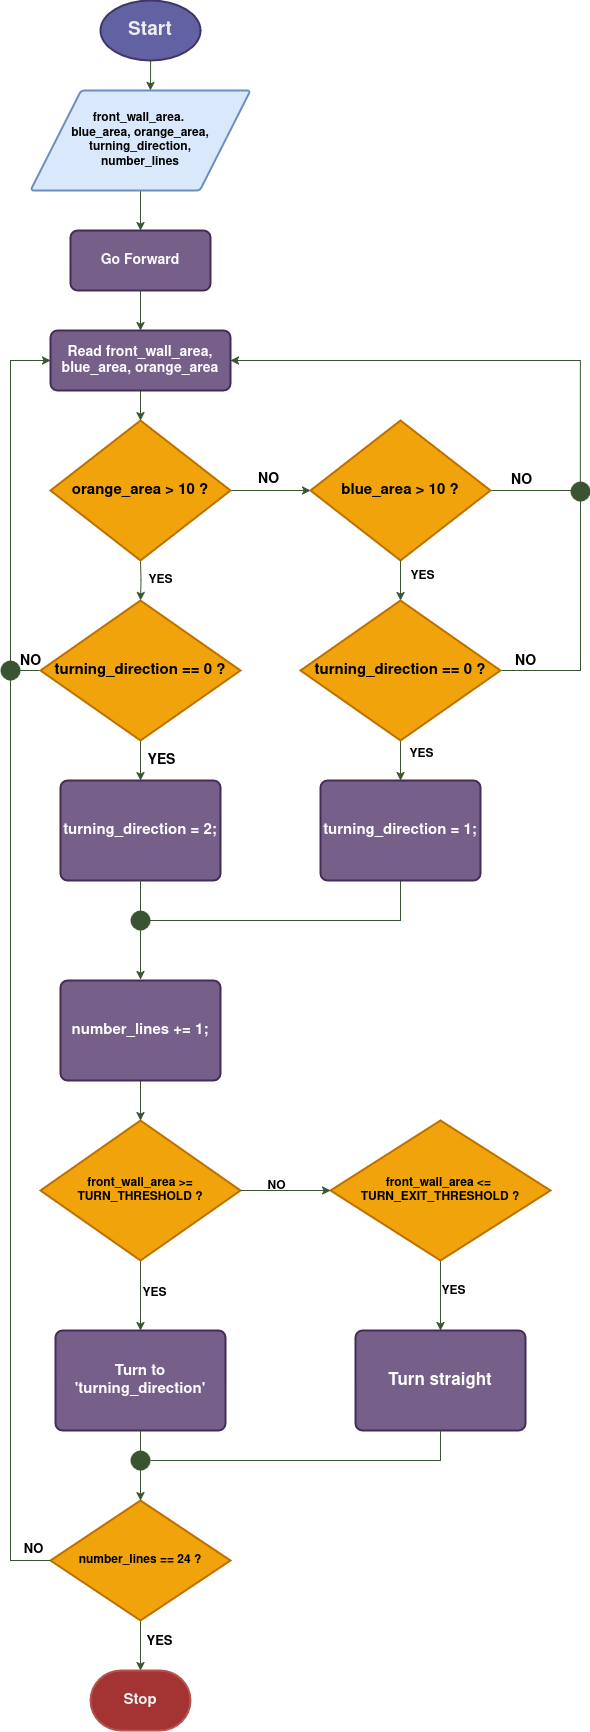
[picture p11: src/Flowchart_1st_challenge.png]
Diagram


</div>

So, here's how our robot makes its decisions during the competition. When we start the robot clicking the button, it first initializes all the important variables it needs to navigate—like `front_wall_area`, `blue_area`, `orange_area`, and `turning_direction`. These help it understand what’s going on around it based on camera input. Then, the robot starts moving forward, constantly scanning its surroundings using its vision system to detect colors and obstacles in real time.

Now, here's where the smart part comes in. If the robot sees a big orange area, it knows it should turn right, and if it sees a big blue area, it decides to turn left—but only if it hasn’t already chosen a direction. It also keeps track of how many lines or segments it has passed using the `number_lines` counter. When it detects a wall directly in front of it beyond a certain threshold, it turns accordingly. But if the obstacle disappears, it just goes straight again. This helps the robot react dynamically to the environment without needing exact pre-programmed paths.

And finally, once the robot completes 24 line crossings, which means it’s finished navigating the full course, it stops automatically. This whole process lets our robot make decisions on the fly, adapting to the track while staying fast and efficient—super.

### Recomendations

We recommend to use another camera with better field of view to make easier to build betters the ROIs to manage every case, because if our car for anything turns bad it could go straight to the wall. 

## Obstacle challenge

### Strategy

In this year’s WRO challenge, our robot uses a combination of color detection and obstacle avoidance to navigate the course efficiently. The main idea is that if there are no obstacles, the robot keeps moving forward just like in the previous challenge , following lines and turning based on blue and orange regions detected by the camera. However, when an obstacle is detected , the robot must make smart decisions depending on the color of the obstacle  and its position relative to the robot .

f the robot detects a red obstacle : 

    And it’s on the right side , the robot turns left  to avoid it.
    But if the red obstacle is on the left side , the robot simply moves forward , assuming it can safely pass on the right.

When a green obstacle  is detected: 

    If it’s on the right side , the robot turns right  to go around it.
    If it’s on the left side , the robot again moves forward , expecting a clear path to the right.

This logic allows the robot to dynamically adjust its path while staying within the boundaries of the track. By combining line-following behavior with intelligent obstacle avoidance based on color and position, our robot can complete the course smoothly and efficiently—just what we need for a strong performance in the WRO competition! 

### Flowchart

<div align="center">

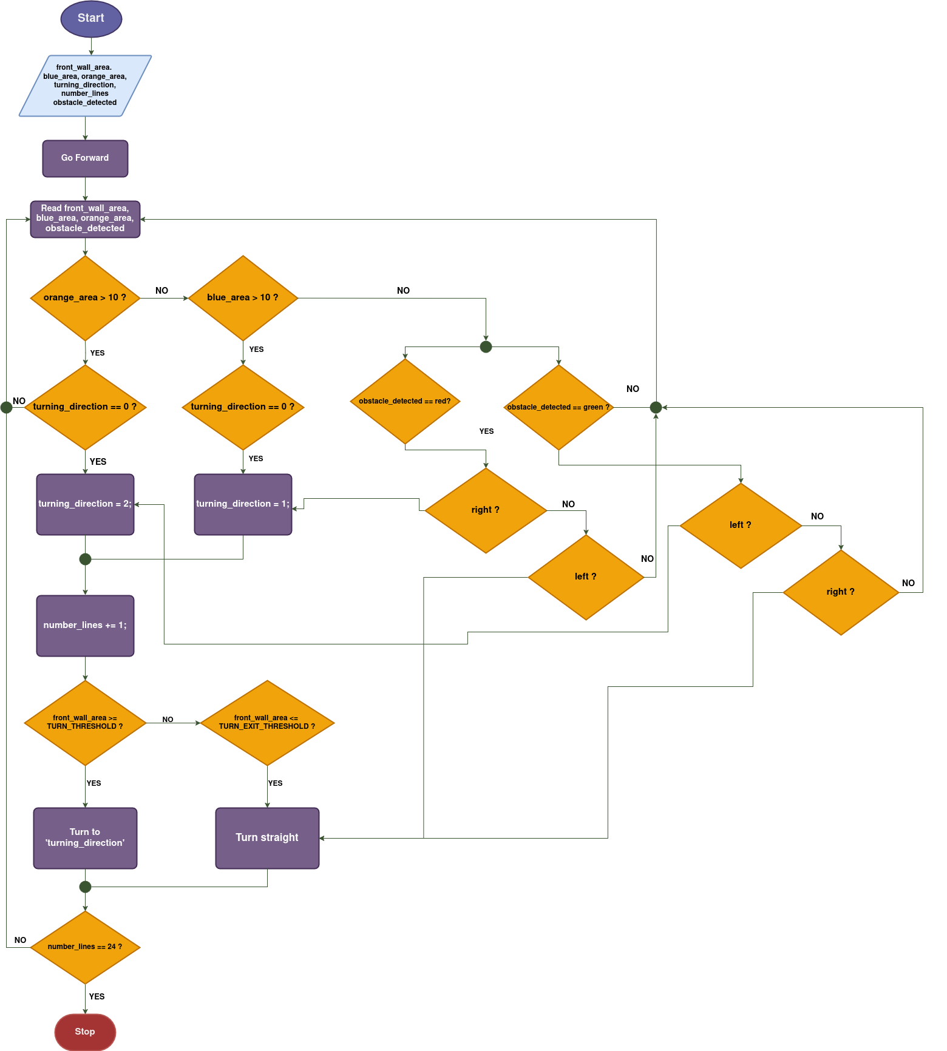
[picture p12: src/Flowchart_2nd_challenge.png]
2nd challenge


</div>

The robot begins by initializing key variables like `front_wall_area`, `blue_area`, `orange_area`, `turning_direction`, and `obstacle_detected` to help interpret its surroundings using sensor data. It then starts moving forward while continuously scanning for colors and obstacles. If it detects a significant orange area, it sets the turning direction to right, or left for blue—only if no direction was previously set. The robot also checks for red or green obstacles and decides the best way to avoid them by adjusting its turning direction accordingly.

As it navigates, the robot keeps track of how many lines or segments it has passed using the `number_lines` counter. When it senses a wall directly ahead beyond a certain threshold, it follows the chosen turning direction. Once it clears the obstacle, it continues straight again. This process repeats until it completes 24 line crossings, signaling the end of the course. This logic allows the robot to react quickly and efficiently to its environment, making real-time decisions that are crucial for success.

### Recomendations

A key recommendation we’d give to other teams competing in WRO is to invest time and effort into using a camera with computer vision (CV)  rather than relying solely on basic color sensors. While simple sensors can detect colors, they only give limited information — usually from a very small area and without any idea of position or size. In contrast, a camera allows you to detect not just what color is present, but also where  it is located and how much space it occupies in the frame. This makes your robot capable of distinguishing between obstacles on the left or right side, identifying which way to turn safely, and even ignoring small reflections or false readings that might confuse a basic sensor. 

Using computer vision also gives your robot more flexibility in handling complex tasks like avoiding red or green obstacles based on their position, as seen in this year’s challenge. With a camera, you can divide the image into regions of interest (like left, center, and right), process multiple colors at once, and make smarter navigation decisions in real time. Additionally, detecting the size of the color area  helps avoid unnecessary reactions to small patches or lighting noise, making your system more stable and reliable. When combined with other sensors like ultrasonic or infrared for distance measurement, CV creates a powerful perception system that allows your robot to move confidently through the course, even under varying conditions. 
</div>

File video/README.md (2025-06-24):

Video
====

## First challenge

<div align="justify">

<div align="center">
Click me!

Vista previa del video (https://www.youtube.com/watch?v=lOoVugvAw2w)

</div>

In the first challenge  of the WRO 2025 FE category, Our vehicle have to be capable of navigating a dynamic track that changes in each round. The robot starts from a randomly assigned section determined by a coin toss. The robot must detect the walls or the lines to know when to stop using its sensors or vision system. This challenge tests the team’s ability to implement reliable line detection , real-time decision making , and precise steering control , all while dealing with varying track widths and randomized obstacle placement in later rounds.

</div>

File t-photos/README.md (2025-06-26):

Team's photos
====

This directory must contain 2 photos of the team (an official one and one funny photo with all team members)

# Funny pic
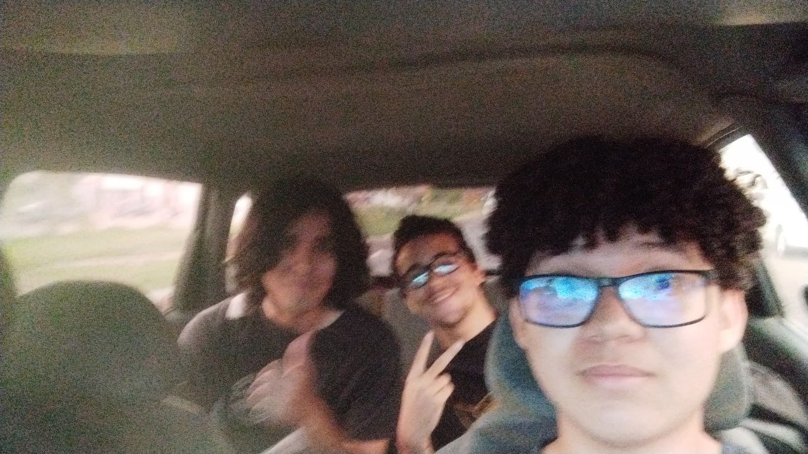
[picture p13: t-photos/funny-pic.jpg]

# Team pic
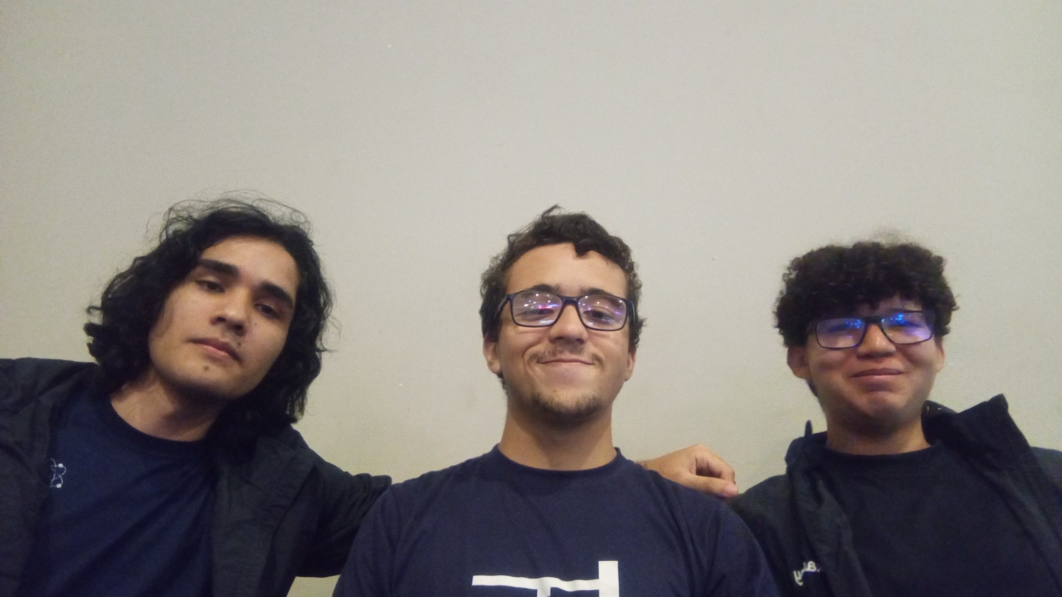
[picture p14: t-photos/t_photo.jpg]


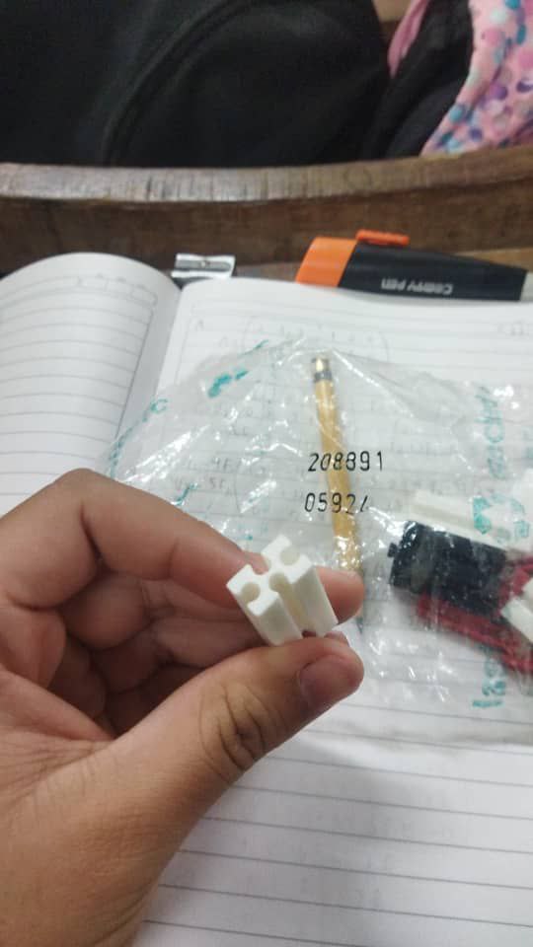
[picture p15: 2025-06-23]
schemes/Artificial-conection.jpg

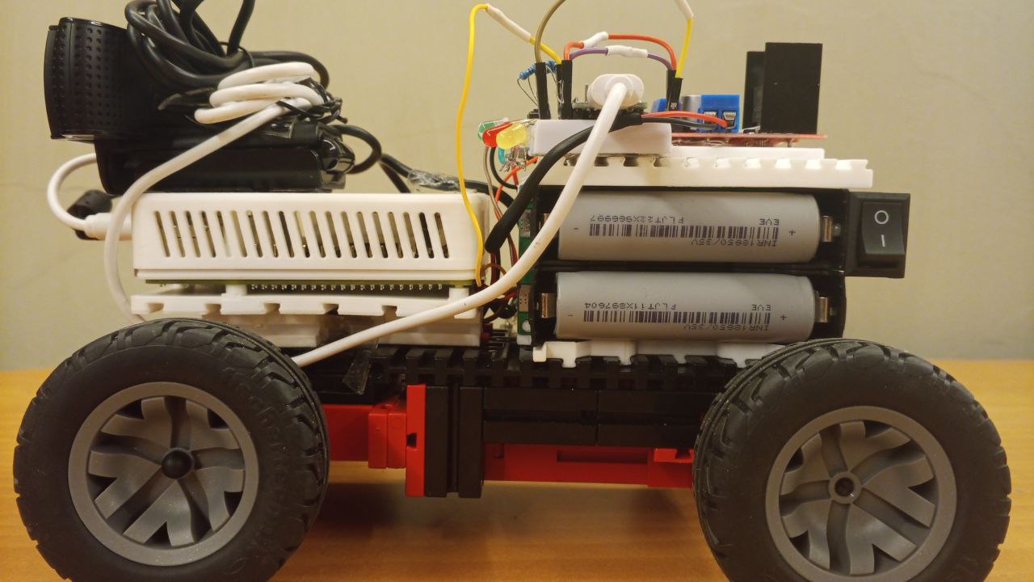
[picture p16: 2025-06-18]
v-photos/left.jpg

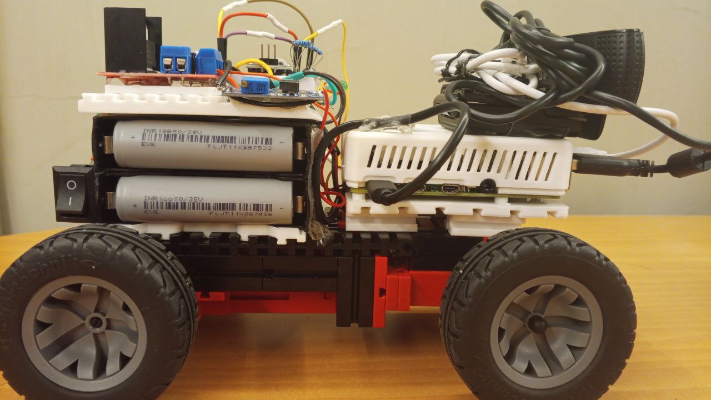
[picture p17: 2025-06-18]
v-photos/right.jpg

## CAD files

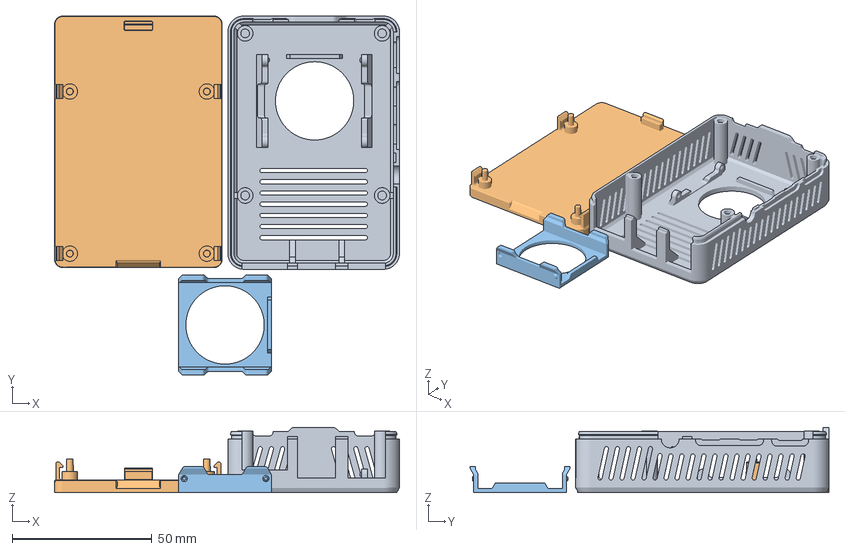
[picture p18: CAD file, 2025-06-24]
models/Raspberry4_Base.3mf
123.4 x 128.4 x 23.4 mm
picase new-Top_H20_Slots_SM_Fan40_Rails.stl
ft_RaspberryPi-Housing_flat.stp
Fan30_Sled.stl

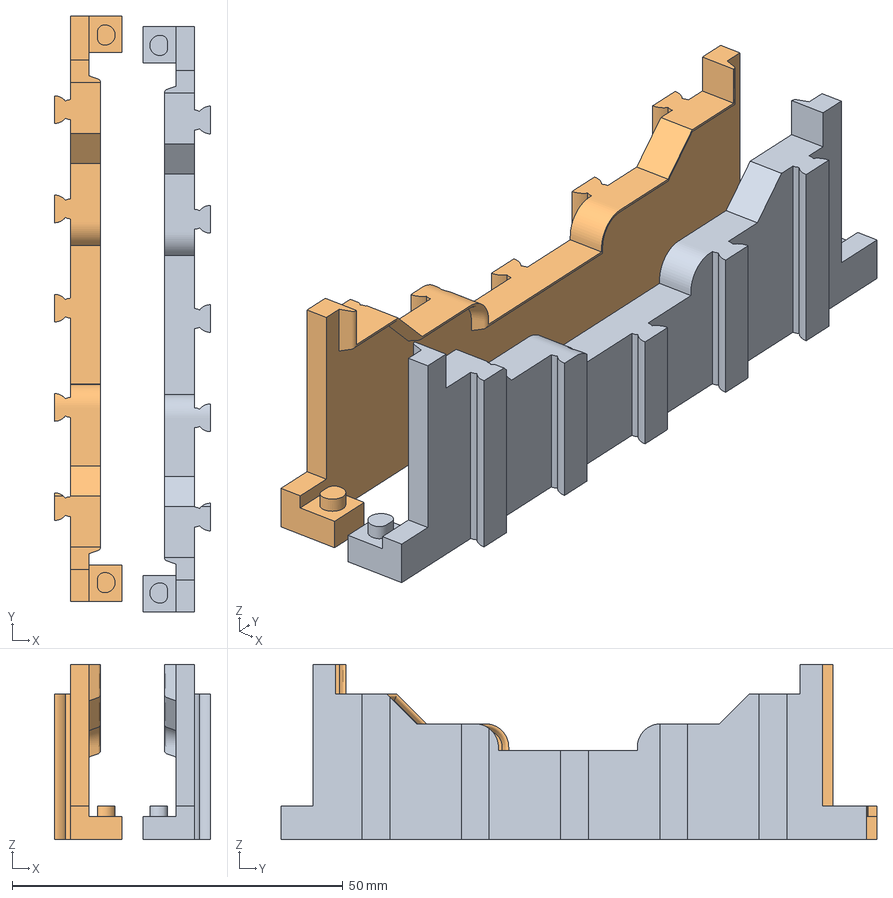
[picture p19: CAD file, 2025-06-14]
models/LX-2BUPS_Down_Base.3mf
23.6 x 90.1 x 26.5 mm
Base izquierda x 2

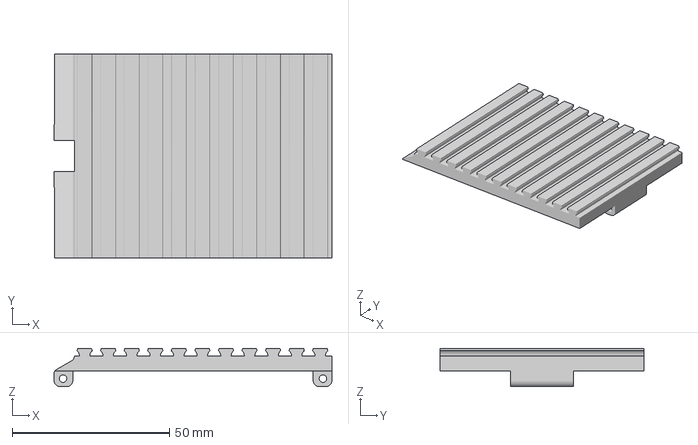
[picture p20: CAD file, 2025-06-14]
models/Top_Base.3mf
88.5 x 65.0 x 12.2 mm

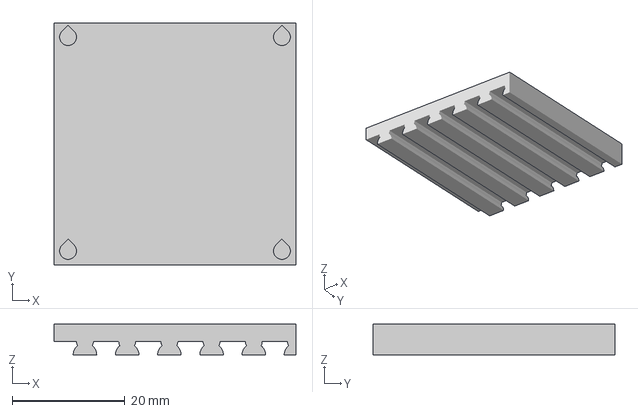
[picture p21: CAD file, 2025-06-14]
models/L298N_Base.3mf
43.0 x 43.0 x 5.50 mm

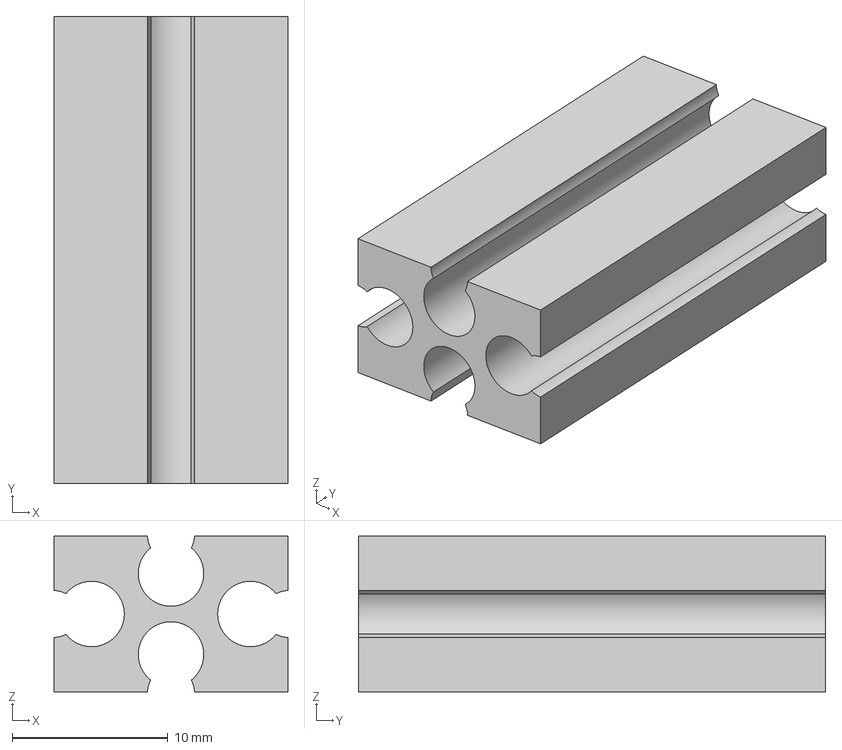
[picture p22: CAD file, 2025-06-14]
models/Base_Extension.3mf
15.0 x 30.0 x 10.0 mm

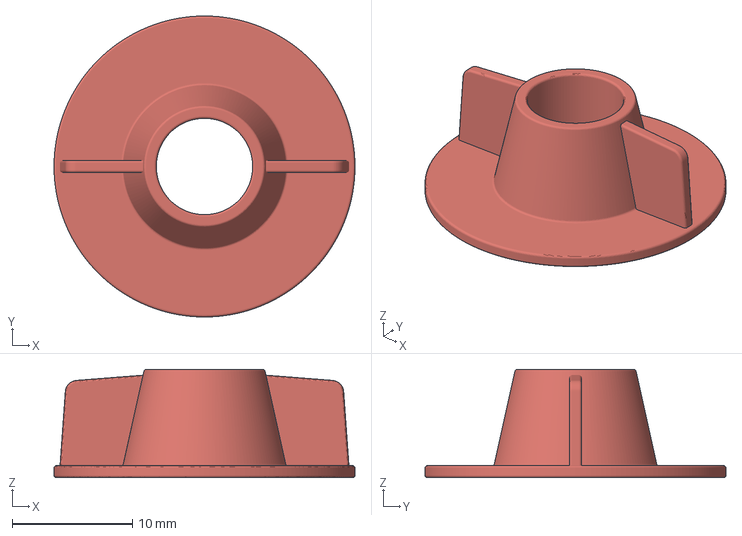
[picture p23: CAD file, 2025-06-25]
models/wheel_nut.3mf
25.0 x 25.0 x 9.00 mm

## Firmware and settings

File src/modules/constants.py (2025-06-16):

from dataclasses import dataclass

# Region Of Interest:
#
#  x1,y1----------------
#  |                    |
#  |                    |
#  |                    |
#  -------------------x2,y2   

@dataclass
class ROI:
    """Recive two points from the frame  to extract the Region Of Interest"""

    x1: int; y1: int
    x2: int; y2: int


# Motor PINS
IN_3 = 12
IN_4 = 11
ENB = 10 # ENABLE
# Servo PINS and VALUES
SERVO_PIN = 9

RIGHT = 0
LEFT = 180
CENTER = 90

# LEDS PINS
LED_YELLOW = 7
LED_RED = 6
LED_WHITE = 5
LED_GREEN = 4

# Buton pin
BUTTON = 3
# Arduino pins
PINS = {
        "LED": [LED_YELLOW, LED_RED, LED_WHITE, LED_GREEN],
        "BUZZER": None, 
        "SERVO": SERVO_PIN,
        "MOTOR_EN": ENB,
        "MOTOR_IN3": IN_3,
        "MOTOR_IN4": IN_4,
        "BUTTON": BUTTON
}

RED_TARGET = 110 
GREEN_TARGET = 530


# Open Challenge regions
#OPEN_ROI_LEFT = ROI(0, 0, 60, 479)
#OPEN_ROI_RIGHT = ROI(1280 - 100, 0, 1280, 720)
CENTER_X = int(640 / 2)
CENTER_Y = int(480 / 2) + 30
OPEN_ROI_CENTER = ROI(CENTER_X - 150,CENTER_Y - 50,CENTER_X + 150,450)
ROI_LINES = ROI(200, 370, 440, 470)

TURN_THRESH = 30000.0
TURN_EXIT_THRESH = 12000.0

# Obstacle Challenge regions

#ROI_LEFT_LANE = ROI(0, 175, 330, 265)
#ROI_RIGHT_LANE = ROI(330, 175, 640, 265)


ROI_PILLARS = ROI(RED_TARGET - 50, 120, GREEN_TARGET + 50, 345)

ROI_CORNERS = ROI(270, 120, 370, 140) #270, 120, 370, 140

#OBSTACLE_ROI_CENTER = ROI()


# Color masks for detecting obstacles
# The colorspace used is HSV
# H: Hue (From 0 to 180)
# S: Saturation
# V: Value

'''
              #lower range        # upper range
mask_red    = [ [160, 120, 40], [180, 255, 255]]
mask_green  = [  [40, 120, 40], [80, 255, 255] ]
mask_black =  [ [0, 0, 0], [180, 255, 75] ]
mask_orange = [ [30, 120, 40],     [30, 255, 255]]
mask_blue   = [ [30,120,40],         [30,255,255]]

'''

# Color masks in LAB colorspace


mask_red = [[0, 153, 140], [ 131,198, 171]]
mask_green = [[0, 45, 0], [255, 117, 153]]

mask_blue = [[54, 124, 25], [148, 164, 121]]
mask_blue_test = [[97, 127, 88], [158, 145, 99]]

mask_orange = [[0, 163, 163], [255, 191, 204]]
mask_orange_test = [[89, 132, 109], [159, 149, 134]]

mask_black = [[0, 109, 113], [59, 137, 150]]
mask_black_test = [[0, 0, 95], [84, 255, 122]]

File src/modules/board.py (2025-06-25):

import time
import pyfirmata2
from src.constants import *

class ArduinoController:
    def __init__(self, port=None):
        """
        Initializes the connection with Arduino.
        If no port is specified, it attempts to autodetect.
        """
        # If port is not provided, auto_setup returns the proper port
        self.board = pyfirmata2.Arduino(port)

        # Start the iterator to continuously read data from Arduino
        self.iterator = pyfirmata2.util.Iterator(self.board)
        self.iterator.start()

        # Dictionaries to store components
        self.servos = {}
        self.motors = {}
        self.leds = {}
        self.buzzers = {}
        self.buttons = {}

    def setup_led(self, pin: int):
        """Configures an LED on the specified pin."""
        self.leds[pin] = self.board.get_pin(f'd:{pin}:o')

    def led_on(self, pin: int):
        """Turns on the LED."""
        self.leds[pin].write(1)

    def led_off(self, pin: int):
        """Turns off the LED."""
        self.leds[pin].write(0)

    def setup_buzzer(self, pin: int):
        """Configures a buzzer on the specified pin."""
        self.buzzers[pin] = self.board.get_pin(f'd:{pin}:o')

    def buzzer_on(self, pin: int):
        """Activates the buzzer."""
        self.buzzers[pin].write(1)

    def buzzer_off(self, pin: int):
        """Deactivates the buzzer."""
        self.buzzers[pin].write(0)

    def setup_servo(self, pin: int):
        """Configures a servo on the specified pin."""
        self.servos[pin] = self.board.get_pin(f'd:{pin}:s')  # Servo mode
        self.servos[pin].write(CENTER)
        time.sleep(0.1)  # Small pause for initialization

    def set_servo_angle(self, pin: int, angle: float):
        """Sets the servo angle (0-180 degrees)."""
        self.servos[pin].write(angle)

    def setup_motor(self, in1_pin: int, in2_pin: int, motor_id: str, enb_pin:int):
        """
        Configures a DC motor using the DRV8833 driver.
        For l298n, two control signals (in1 and in2) are used.
        The motor_id is an identifier for storing this motor's configuration.
        """
        self.motors[motor_id] = {
            'in1': self.board.get_pin(f'd:{in1_pin}:o'),  # PWM capable pin
            'in2': self.board.get_pin(f'd:{in2_pin}:o'),   # PWM capable pin
            'eb': self.board.get_pin(f'd:{enb_pin}:p')   # PWM capable pin
        }

    def set_motor_speed(self, motor_id: str, speed: int):
        """
        Controls the speed and direction of the motor (-255 to 255) using DRV8833.
        If speed > 0: forward, if speed < 0: reverse, and if speed == 0: stop.
        """
        # Limit the speed to the range -255 to 255
        normalized_speed = abs(speed) / 255.0  # Normalize to 0-1 for PWM

        motor = self.motors[motor_id]

        if speed > 0:
            # Forward: PWM on in1, in2
            motor['eb'].write(normalized_speed)
            motor['in1'].write(1)
            motor['in2'].write(0)
        elif speed < 0:
            # Reverse: in1 low, PWM on in2
            motor['eb'].write(normalized_speed)
            motor['in1'].write(0)
            motor['in2'].write(1)
        else:
            # Stop motor: both signals low
            motor['eb'].write(0)
            motor['in1'].write(0)
            motor['in2'].write(0)
            
    def setup_button(self, pin: int):
        """
            Configures a button on the specified pin with internal pull-up resistor.
            Returns the pin object for direct access if needed.
        """
        button_pin = self.board.get_pin(f'd:{pin}:u')
        button_pin.register_callback(lambda data: self.button_callback(data, pin))
        button_pin.enable_reporting()
        self.buttons[pin] = button_pin
        self.buttons[pin].state = True
    
    def button_callback(self, data, pin:int):
        """
        Se llama automáticamente cuando cambia el estado del botón
        data == 1 -> Botón suelto (HIGH)
        data == 0 -> Botón presionado (LOW)
        """
        self.buttons[pin].state = data
        
    def is_button_pressed(self, pin: int):
        """
        Return:
            true if the button is released, otherwise false
        """
        return self.buttons[pin].state
    
    def interactive_test_menu(self):
        """Interactive console menu to test LEDs, buttons, motors, and servos."""
        while True:
            print("\n=== Menú de Pruebas ===")
            print("1. Probar LED")
            print("2. Probar Botón")
            print("3. Probar Motor")
            print("4. Probar Servo")
            print("5. Salir")
            choice = input("Selecciona una opción (1-5): ")

            try:
                choice = int(choice)
            except ValueError:
                print("Opción inválida. Por favor ingresa un número entre 1 y 5.")
                continue

            if choice == 1:
                # Test LED
                pin = int(input("Introduce el pin del LED (ej. 4): "))
                self.setup_led(pin)
                print("Encendiendo LED...")
                self.led_on(pin)
                time.sleep(1)
                print("Apagando LED...")
                self.led_off(pin)

            elif choice == 2:
                # Test Button
                pin = int(input("Introduce el pin del botón (ej. 3): "))
                self.setup_button(pin)
                print(f"Esperando presión del botón en pin {pin}. Presiona Ctrl+C para salir...")
                try:
                    while True:
                        print(self.is_button_pressed(pin))
                        time.sleep(0.1)
                except KeyboardInterrupt:
                    print("Saliendo de la prueba del botón.")

            elif choice == 3:
                # Test Motor
                in1 = int(input("Pin IN1 del motor (ej. 12): "))
                in2 = int(input("Pin IN2 del motor (ej. 11): "))
                en = int(input("Pin ENB del motor (ej. 10): "))
                motor_id = input("Nombre del motor (ej. 'back'): ")

                self.setup_motor(in1, in2, motor_id, en)
                print(f"Motor '{motor_id}' configurado. Probando movimiento...")

                speed = int(input("Velocidad del motor (-255 a 255): "))
                duration = float(input("Duración del movimiento (segundos): "))

                self.set_motor_speed(motor_id, speed)
                print(f"Moviendo motor '{motor_id}' durante {duration}s...")
                time.sleep(duration)
                self.set_motor_speed(motor_id, 0)

            elif choice == 4:
                # Test Servo
                pin = int(input("Pin del servo (ej. 9): "))
                self.setup_servo(pin)
                print(f"Servo en pin {pin} configurado.")
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

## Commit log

2025-02-18 feat(board): Arduino board class added
2025-03-07 Refactor(habi,vision,board,constants): some commets was changed to pydocs format and speed method was renamed
2025-06-13 Button logic added and one interface for debbuging
2025-06-14 Add files via upload
    Models used for the robot
    [Base hw-095.3mf, Base izquierda.3mf, Base superior.3mf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]
2025-06-18 Wiring diagram added
2025-06-18 Wiring diagram updated
2025-06-23 schemes readme was updated with the principal readme
    [Base l298n.3mf]
2025-06-24 Add files via upload
    Base de RaspBerry Pi 4 para el kit fischertechnik
    [Base de RaspBerry pi 4.3mf]
2025-06-25 Files renamed
    [Base_Extension.3mf, Clip union.3mf, L298N_Base.3mf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]
